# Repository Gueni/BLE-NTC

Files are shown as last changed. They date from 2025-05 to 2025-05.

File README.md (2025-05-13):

# 🔵 BLE-NTC Pipe Temperature Sensor

A compact, battery-powered wireless temperature sensor using an NTC T7335 thermistor and a NINA-B112 BLE module. Designed to clip onto pipes and transmit real-time temperature data via Bluetooth Low Energy (BLE).

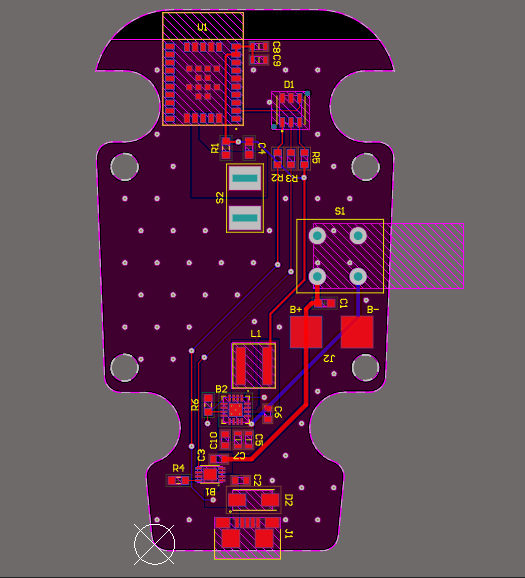
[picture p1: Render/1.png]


## 📦 Overview

This device is a clamp-on wireless temperature sensor for pipes, built around:

- 📡 **NINA-B112**: u-blox BLE module (based on Nordic nRF52832)
- 🌡️ **NTC T7335**: 10kΩ thermistor for precise surface temperature sensing
- 🔋 Battery-powered for low-power remote monitoring
- ⚙️ Custom PCB designed for mechanical stability and thermal coupling

---

## 🛠️ Features

- Accurate pipe surface temperature monitoring
- BLE GATT server for real-time temperature broadcasting
- Low-power design (sleep/wake modes)
- Compact, clamp-mountable PCB layout
- Thermal paste contact zone for improved temperature accuracy

---

## 🔧 Hardware Specs

| Feature | Description |
|---|---|
| **Sensor** | NTC T7335 (10kΩ @ 25°C, B ≈ 3977K) |
| **BLE Module** | NINA-B112-00B-00 (internal antenna) |
| **MCU** | Nordic nRF52832 (inside NINA-B112) |
| **Power Supply** | CR2032 coin cell / AA battery / 3.3V ext. |
| **ADC Interface**| Voltage divider with 10kΩ precision resistor |
| **Mounting** | Pipe clamp + thermal interface pad/paste |
| **Firmware** | BLE custom service with temperature char. |

---

## 📡 BLE Service Description

**Custom BLE GATT Service: `0x181A` (Environmental Sensing)**  
| Characteristic | UUID | Format | Description |
|---|---|---|---|
| Temperature | `0x2A6E` | `int16_t` x100 | Pipe surface temperature in °C |
| Battery Level (opt.) | `0x2A19` | `uint8_t` | Battery percentage |
| Device Info (opt.) | `0x180A` | - | Firmware version, model, etc.  |

---

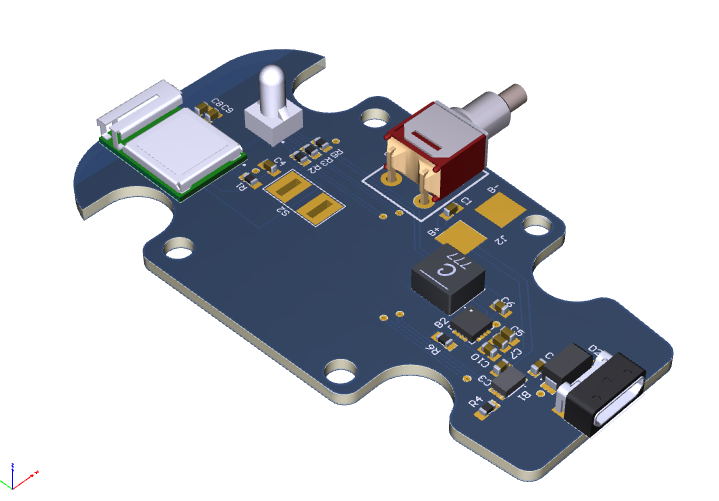
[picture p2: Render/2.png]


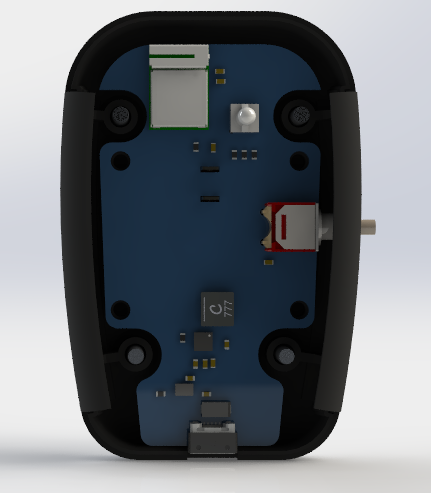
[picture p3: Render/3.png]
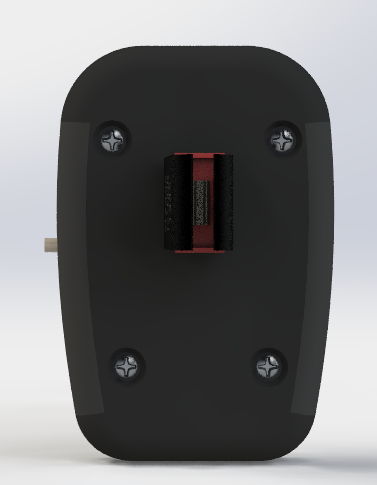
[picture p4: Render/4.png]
 | 

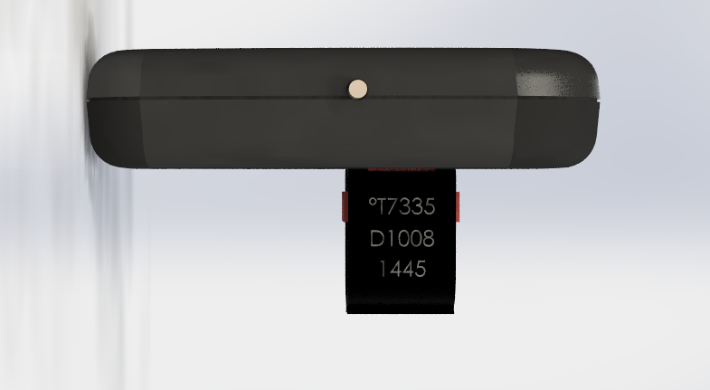
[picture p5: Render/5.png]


---

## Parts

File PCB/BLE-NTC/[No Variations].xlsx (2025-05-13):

Designator | Quantity | DES | FTP | MAN | MANREF | NOTE | SUP | SUPREF | TOL | Value 1 | Value 2
C1, C2 | 2 | Multilayer Ceramic Capacitors MLCC - SMD/SMT 4.7UF 16V 10% 0603 | 0603 | Murata Electronics | GRM188C71C475KE21D | _ | Mouser | 81-GRM188C71C475KE1D | 10% | 4.7uF | 16V
C3, C4 | 2 | 06035C103JAT2A - Condensateur céramique multicouche CMS, 10000 pF, 50 V, 0603 [1608 Metric], ± 5%, X7R | 0603 | MULTICOMP | 06035C103JAT2A | _ | Farnell | 1833871 | 5% | 10nF | 50V
C5, C6, C13 | 3 | C0603X104K8RACTU - Condensateur céramique multicouche CMS, 0.1 µF, 10 V, 0603 [1608 Metric], ± 10%, X7R | 0603 | KEMET | C0603X104K8RACTU | _ | Farnell | 2904937 | 10% | 100nF | 10V
C11 | 1 | Multilayer Ceramic Capacitors MLCC - SMD/SMT 0603 22uF 6.3volts *Derate Voltage/Temp | 0603 | Murata Electronics | GRM188R60J226MEA0D | In Stock | Mouser | 81-GRM188R60J226ME0D | 20% | 22uF | 6V3
C12 | 1 | Multilayer Ceramic Capacitors MLCC - SMD/SMT 0603 10uF 35volts *Derate Voltage/Temp | 0603 | Murata Electronics | GRM188R6YA106MA73D | _ | Mouser | 81-GRM188R6YA106MA3D | 20% | 10uF | 35V
C14 | 1 | Multilayer Ceramic Capacitors MLCC - SMD/SMT 50V 430pF 0603 C0G 0.02 | 0603 | KEMET | C0603C431G5GACTU | In Stock | Mouser | 80-C0603C431G5G | 2% | 430pF | 50V
D1 | 1 | WL-SFTW SMD Full-color TOP LED Waterclear, size 5050, Red & Green & Blue, 120deg | _ | Wurth Elektronik | 150353M153300 | In Stock | Mouser | 710-150353M153300 | _ | 100 mA | _
D2 | 1 | ESD Suppressors / TVS Diodes HJ Temp Transil ESD Suppressors / TVS Diodes HJ Temp Transil | SMA | STMicroelectronics | SMA6J5.0CA-TR | In Stock | Mouser | 511-SMA6J5.0CA-TR | _ | 13.4 V | 600W
J1 | 1 | USB Connectors USB MICRO B TYPE RECPT | SMD | Amphenol Commercial Products | GMCBA058211230HHR | In Stock | Mouser | 523-GMCBA05821123HHR | _ | _ | _
J2 | 1 | Embases et logements de câbles WR-PHD 2.54mm Hdr 6P Dual Str Gold | THT | Wurth Electronics | 61300621121 | In Stock | Mouser | 710-61300621121 | _ | 6pts | _
J3 | 1 | _ | _ | _ | _ | _ | _ | _ | _ | _
L2 | 1 | Fixed Inductors 2.2uH 20% 9.7A 14.5mOhms AEC-Q200 | _ | Coilcraft | XAL5030-222MEB | In Stock | Mouser | 994-XAL5030-222MEB | 20 % | 2.2uH | 9.2 A
Q1 | 1 | NXP NX3008NBK MOSFET, N CH, 30V, 400MA, SOT23 | SOT-23 | NXP | NX3008NBK | In Stock | Farnell | 2069541 | _ | 400mA | 30V
R1 | 1 | YAGEO (PHYCOMP) RC0603FR-0710KL RESISTANCE COUCHE EPAISSE 10K 0.1W 1% | 0603 | YAGEO | RC0603FR-0710KL | _ | Farnell | 9238603 | 1% | 10K | 0.1W
R2 | 1 | Thick Film Resistors 806KOHM 1/10WATT 1% | 0603 | Bourns | CR0603-FX-8063ELF | In Stock | Mouser | 652-CR0603-FX8063ELF | 1% | 806K | 0.1W
R3 | 1 | Thick Film Resistors 1/10watt 160ohms 1% | 0603 | Vishay / Dale | CRCW0603160RFKEA | In Stock | Mouser | 71-CRCW0603-160-E3 | 1% | 160R | 0,1W
R4 | 1 | YAGEO (PHYCOMP) RC0603FR-072K2L RESISTANCE COUCHE EPAISSE 2.2K 0.1W 1% | 0603 | YAGEO | RC0603FR-072K2L | _ | Farnell | 9238522 | 1% | 2K2 | 0.1W
R5, R7 | 2 | Thick Film Resistors 1/10watt 5.1ohms 5% | 0603 | Vishay / Dale | CRCW06035R10JNEA | In Stock | Mouser | 71-CRCW0603J-5.1-E3 | 5% | 5R1 | 10W
R6 | 1 | Thin Film Resistors .1W 2Mohms 1% 0603 50ppm | 0603 | Vishay / Beyschlag | MCT06030C2004FP500 | In Stock | Mouser | 594-MCT06030C2004FP5 | 1% | 2 M | 0.125W
R9 | 1 | YAGEO (PHYCOMP) RC0603FR-07100KL RESISTANCE COUCHE EPAISSE 100K 0.1W 1% | 0603 | YAGEO | RC0603FR-07100KL | _ | Farnell | 9238727 | 1% | 100K | 0.1W
S1 | 1 | Negative temperature coefficient thermistor | _ | Honeywell | T7335 D1008 | _ | _ | _ | _ | _ | _
S2 | 1 | Pushbutton Switches SPDT ON-ON PC MNT | _ | E-Switch | 800CSP1B6M6QE | _ | E-Switch | 800CSP1B6M6QE | _ | _ | _
U1 | 1 | Battery Management Charge mgnt contr Battery Management Charge mgnt contr | DFN | Microchip Technology | MCP73831T-2ACI/MC | In Stock | Mouser | 579-MCP73831T-2ACIMC | _ | _ | _
U2 | 1 | MOD BLE 5.0 NORDIC NRF52832 SOC | _ | U-Blox | NINA-B112-00B-00 | In Stock | Digi-Key | 672-NINA-B112-00B-00CT-ND | _ | _ | _
U4 | 1 | Switching Voltage Regulators 3-17V 3A SD Cnvrtr | VQFN-16 | Texas Instruments | TPS62132RGTR | In Stock | Mouser | 595-TPS62132RGTR | _ | _ | _

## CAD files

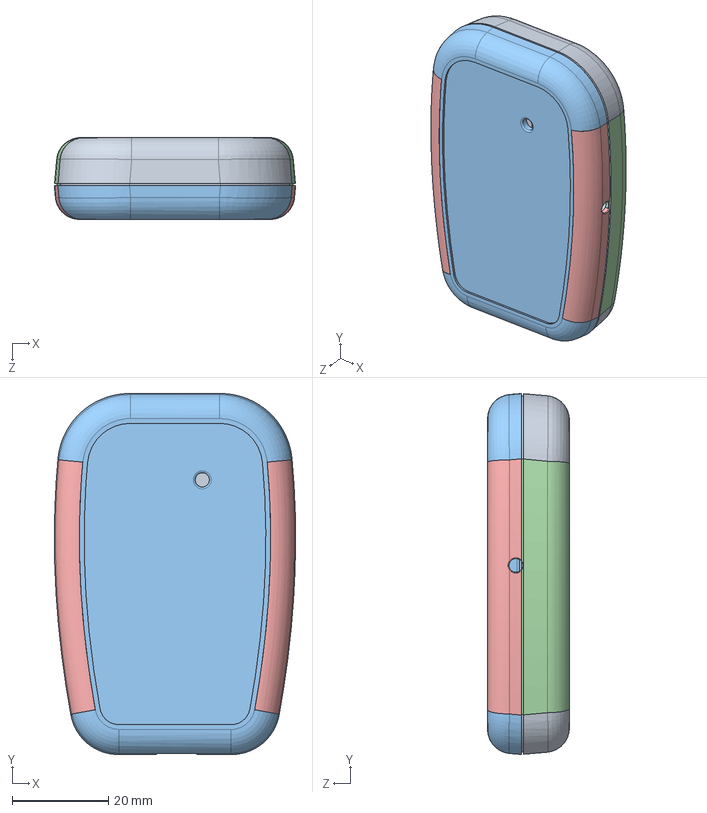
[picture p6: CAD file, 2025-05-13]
3D/Assem2 -nopcb.SLDASM
50.1 x 75.0 x 17.0 mm
1553AA BOTTOM.stp
SC1553A (screw #4X 1_2'' OH).stp x 4
1553AA TOP.stp
1553AA BOTTOM GRIP.stp
1553AA TOP GRIP.stp

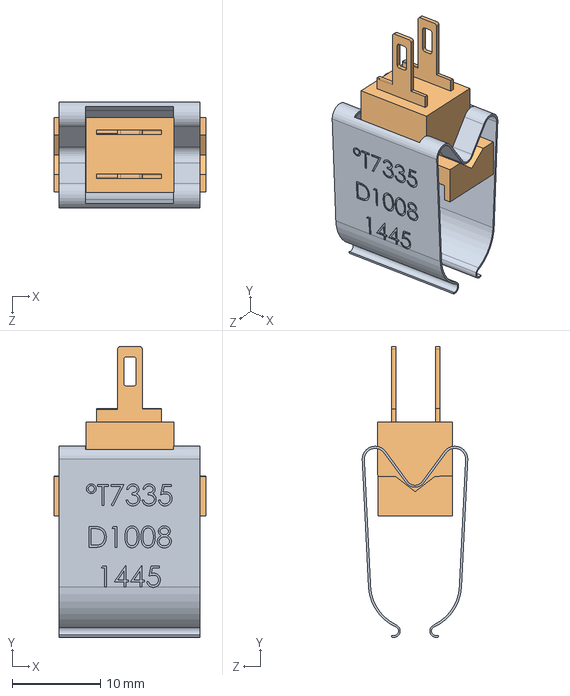
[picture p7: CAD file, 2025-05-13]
3D/T7335D_Assembly.SLDASM
17.2 x 33.0 x 12.0 mm
T7335D
T7335D_sensor

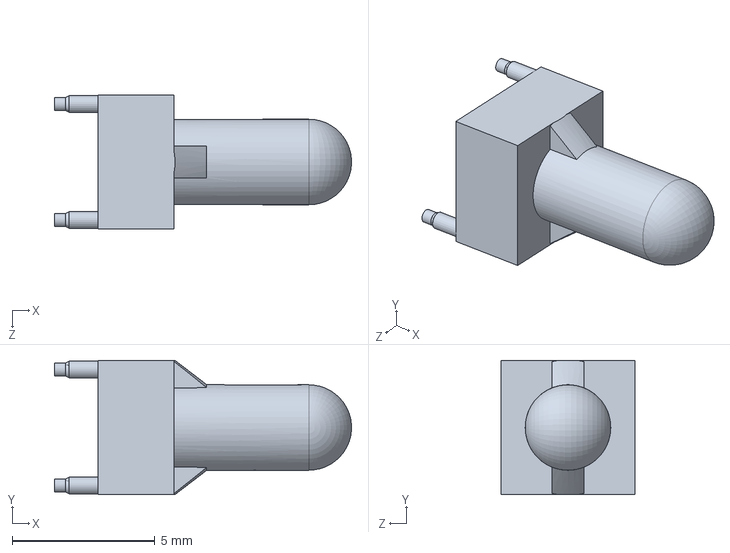
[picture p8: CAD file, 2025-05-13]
3D/VLP-350-R.SLDPRT
10.4 x 4.70 x 4.70 mm

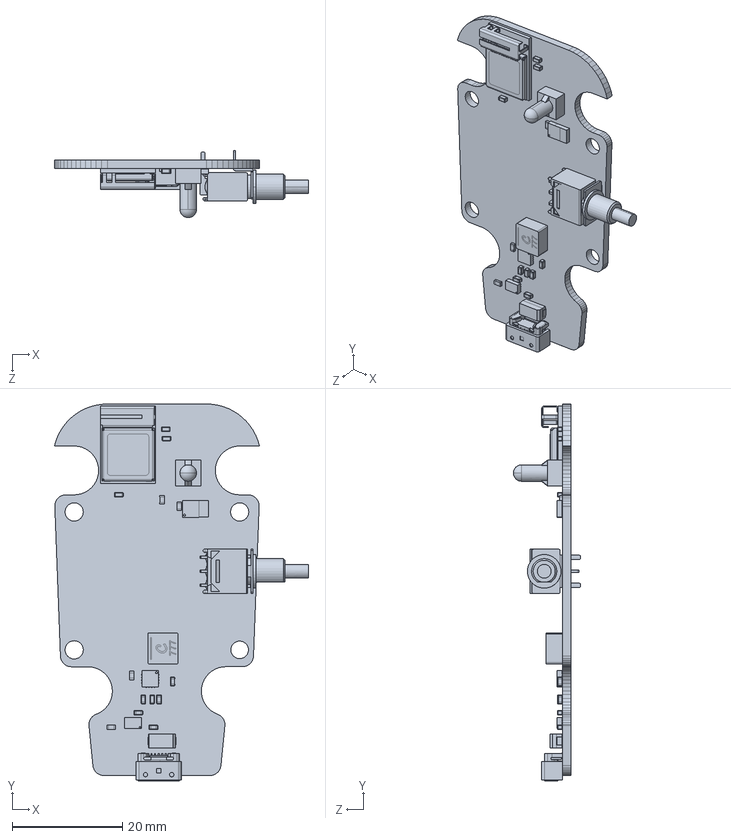
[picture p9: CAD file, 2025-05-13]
3D/Part50.SLDPRT
46.1 x 68.3 x 12.2 mm

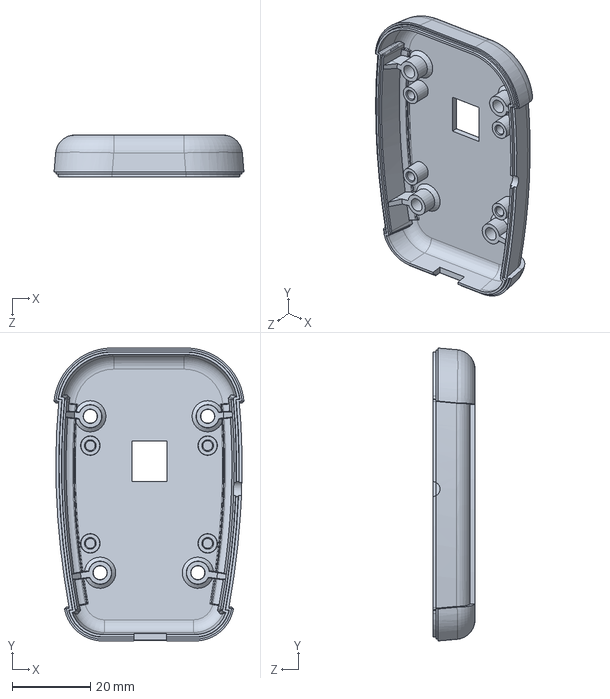
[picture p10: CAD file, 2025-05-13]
3D/1553AA BOTTOM.stp.SLDPRT
48.5 x 74.9 x 10.8 mm

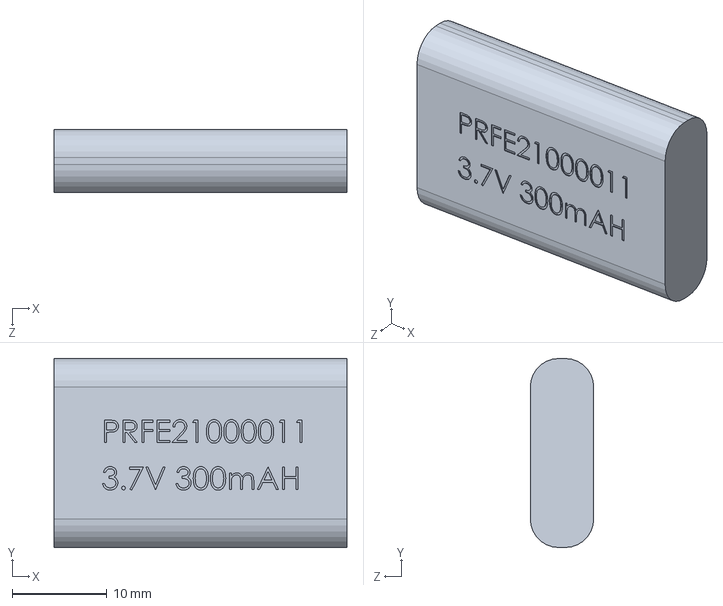
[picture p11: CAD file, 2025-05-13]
3D/Battery_30.0x20.0x6.7.SLDPRT
31.0 x 20.0 x 6.70 mm

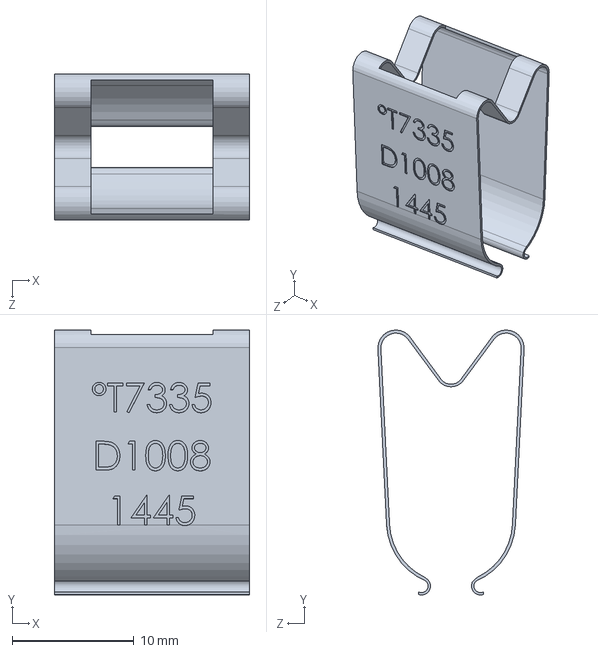
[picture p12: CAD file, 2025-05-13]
3D/T7335D.SLDPRT
16.0 x 21.7 x 12.0 mm

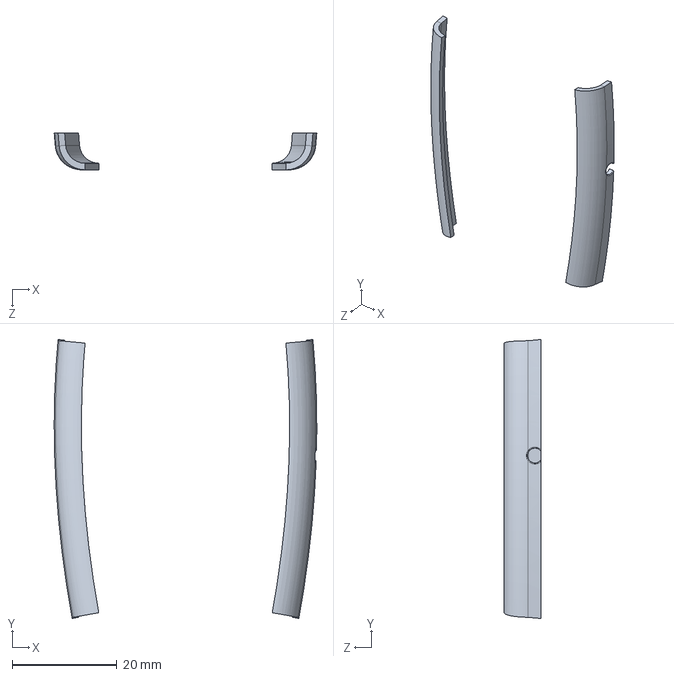
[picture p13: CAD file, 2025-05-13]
3D/1553AA TOP GRIP.stp.SLDPRT
50.1 x 53.3 x 7.00 mm

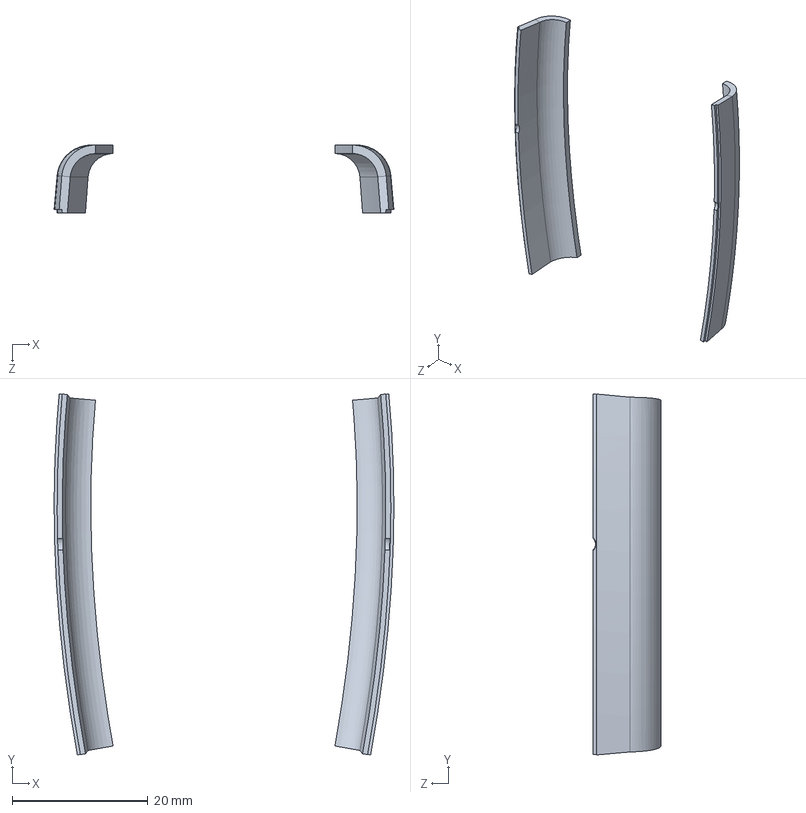
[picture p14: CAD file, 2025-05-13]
3D/1553AA BOTTOM GRIP.stp.SLDPRT
50.0 x 53.2 x 10.0 mm

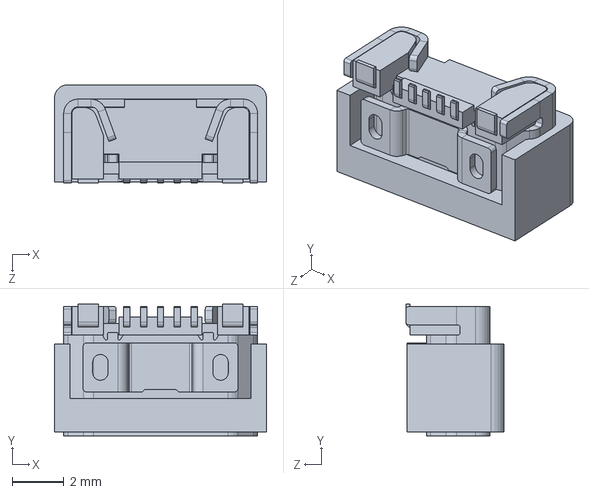
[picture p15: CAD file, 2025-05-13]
3D/gmcba058xx1230hhr.stp.SLDPRT
8.20 x 5.10 x 3.80 mm

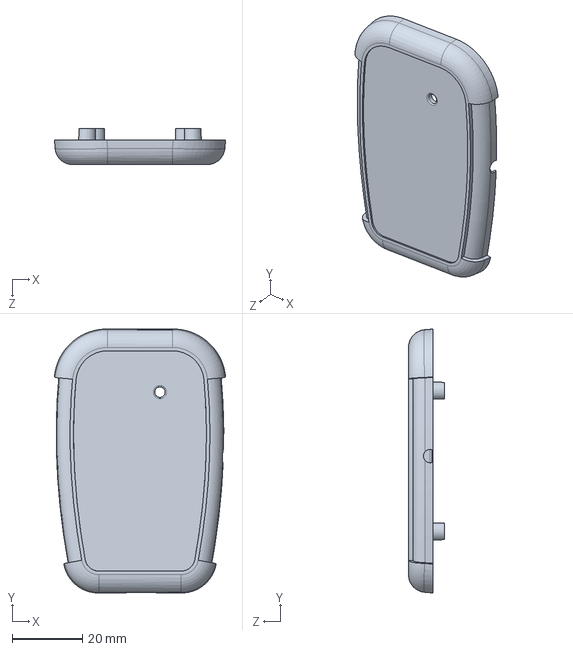
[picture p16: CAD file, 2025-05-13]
3D/1553AA TOP.stp.SLDPRT
48.6 x 75.0 x 10.2 mm

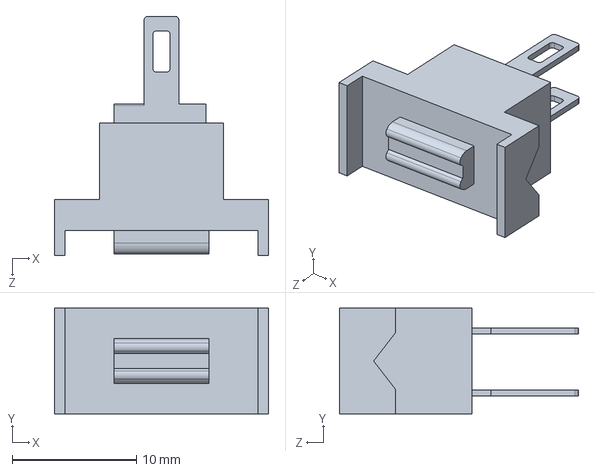
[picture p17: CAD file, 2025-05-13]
3D/T7335D_sensor.SLDPRT
17.2 x 8.50 x 19.2 mm

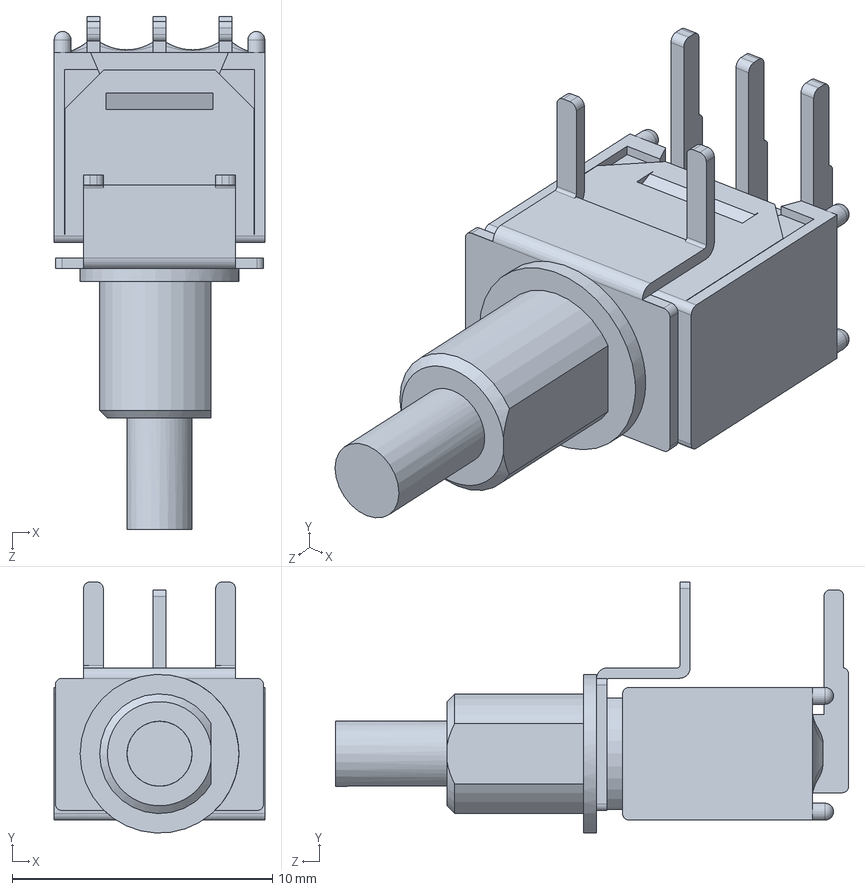
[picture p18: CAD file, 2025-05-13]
3D/800CSP1B6M6xE.stp.SLDPRT
8.10 x 9.65 x 19.7 mm

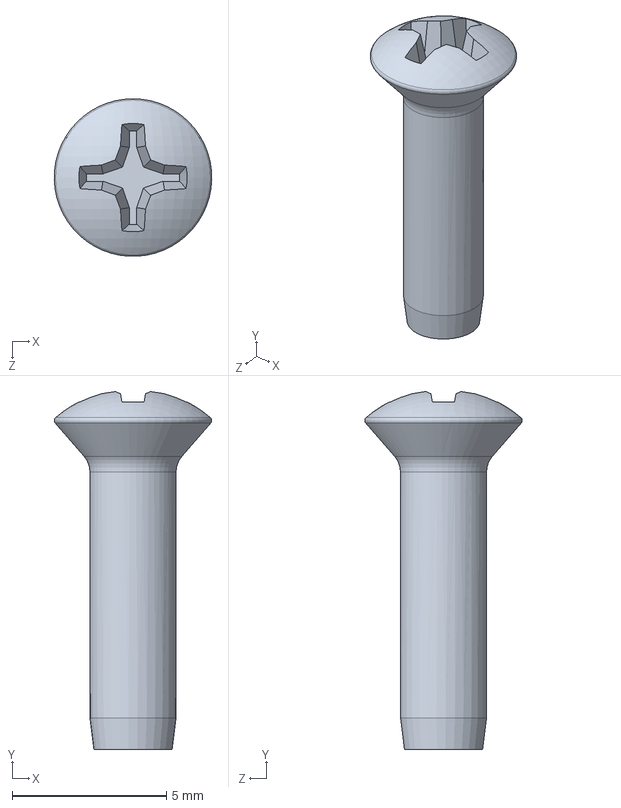
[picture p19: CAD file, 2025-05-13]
3D/SC1553A (screw #4X 1_2'' OH).stp.SLDPRT
5.10 x 11.6 x 5.10 mm

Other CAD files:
3D/00019202.SLDASM
3D/Assembly_without_PCB.SLDDRW
3D/T7335D_Assembly.SLDPRT

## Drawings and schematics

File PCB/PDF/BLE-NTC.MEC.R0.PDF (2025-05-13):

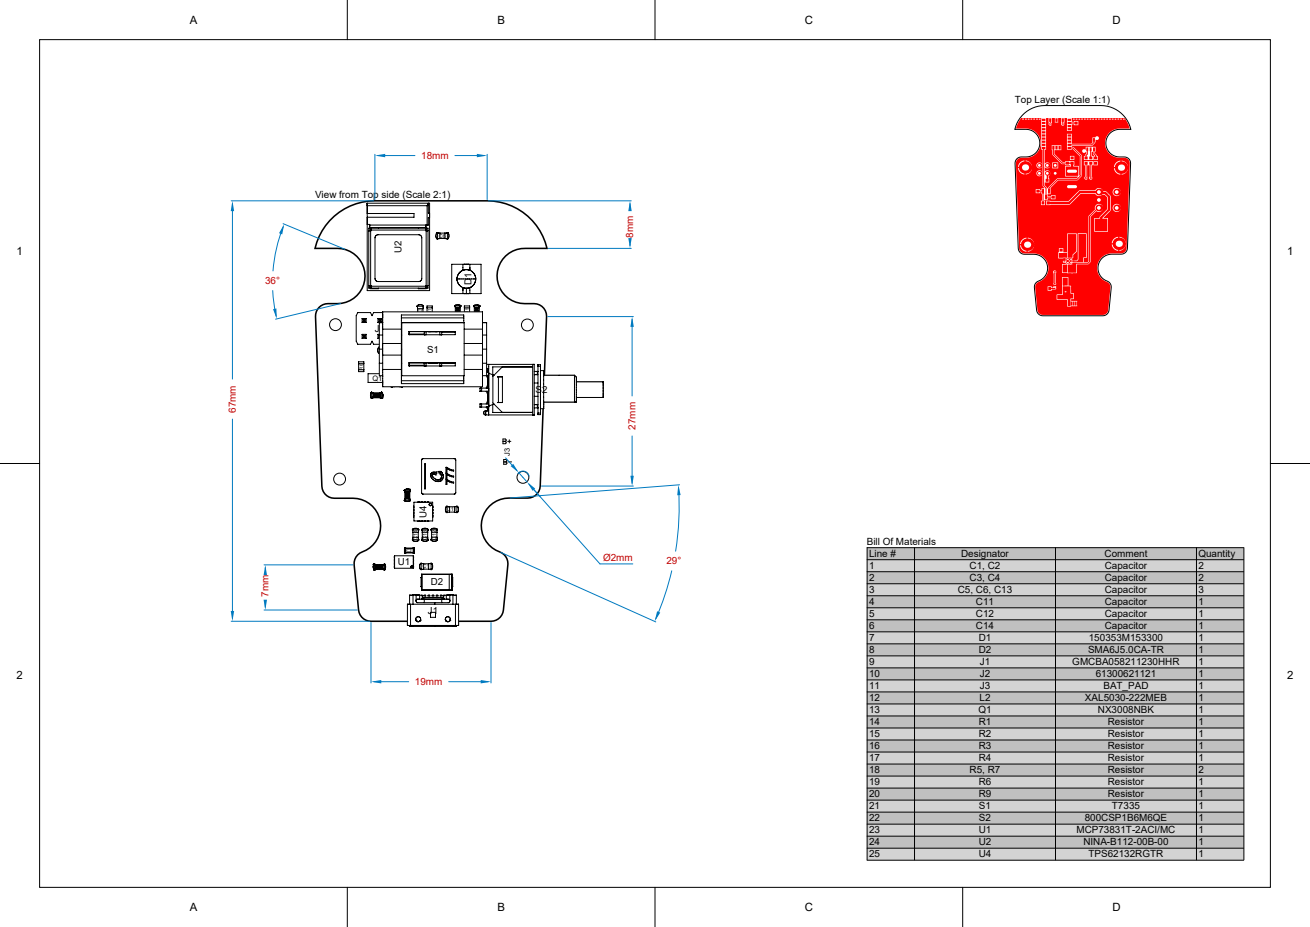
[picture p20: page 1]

View from Top side (Scale 2:1)

Line # 123456789 | C5, C6, C13 | Capacitor

D2 | SMA6J5.0CA-TR | Quantity 2231111111111111121111111
Designator | Comment
C1, C2 | Capacitor
C3, C4 | Capacitor

C11 | Capacitor
C12 | Capacitor
C14 | Capacitor
D1 | 150353M153300

J1 | GMCBA058211230HHR

10 | J2 | 61300621121
11 | J3 | BAT_PAD
12 | L2 | XAL5030-222MEB
13 | Q1 | NX3008NBK
14 | R1 | Resistor
15 | R2 | Resistor
16 | R3 | Resistor
17 | R4 | Resistor
18 | R5, R7 | Resistor
19 | R6 | Resistor
20 | R9 | Resistor
21 | S1 | T7335
22 | S2 | 800CSP1B6M6QE
23 | U1 | MCP73831T-2ACI/MC
24 | U2 | NINA-B112-00B-00
25 | U4 | TPS62132RGTR

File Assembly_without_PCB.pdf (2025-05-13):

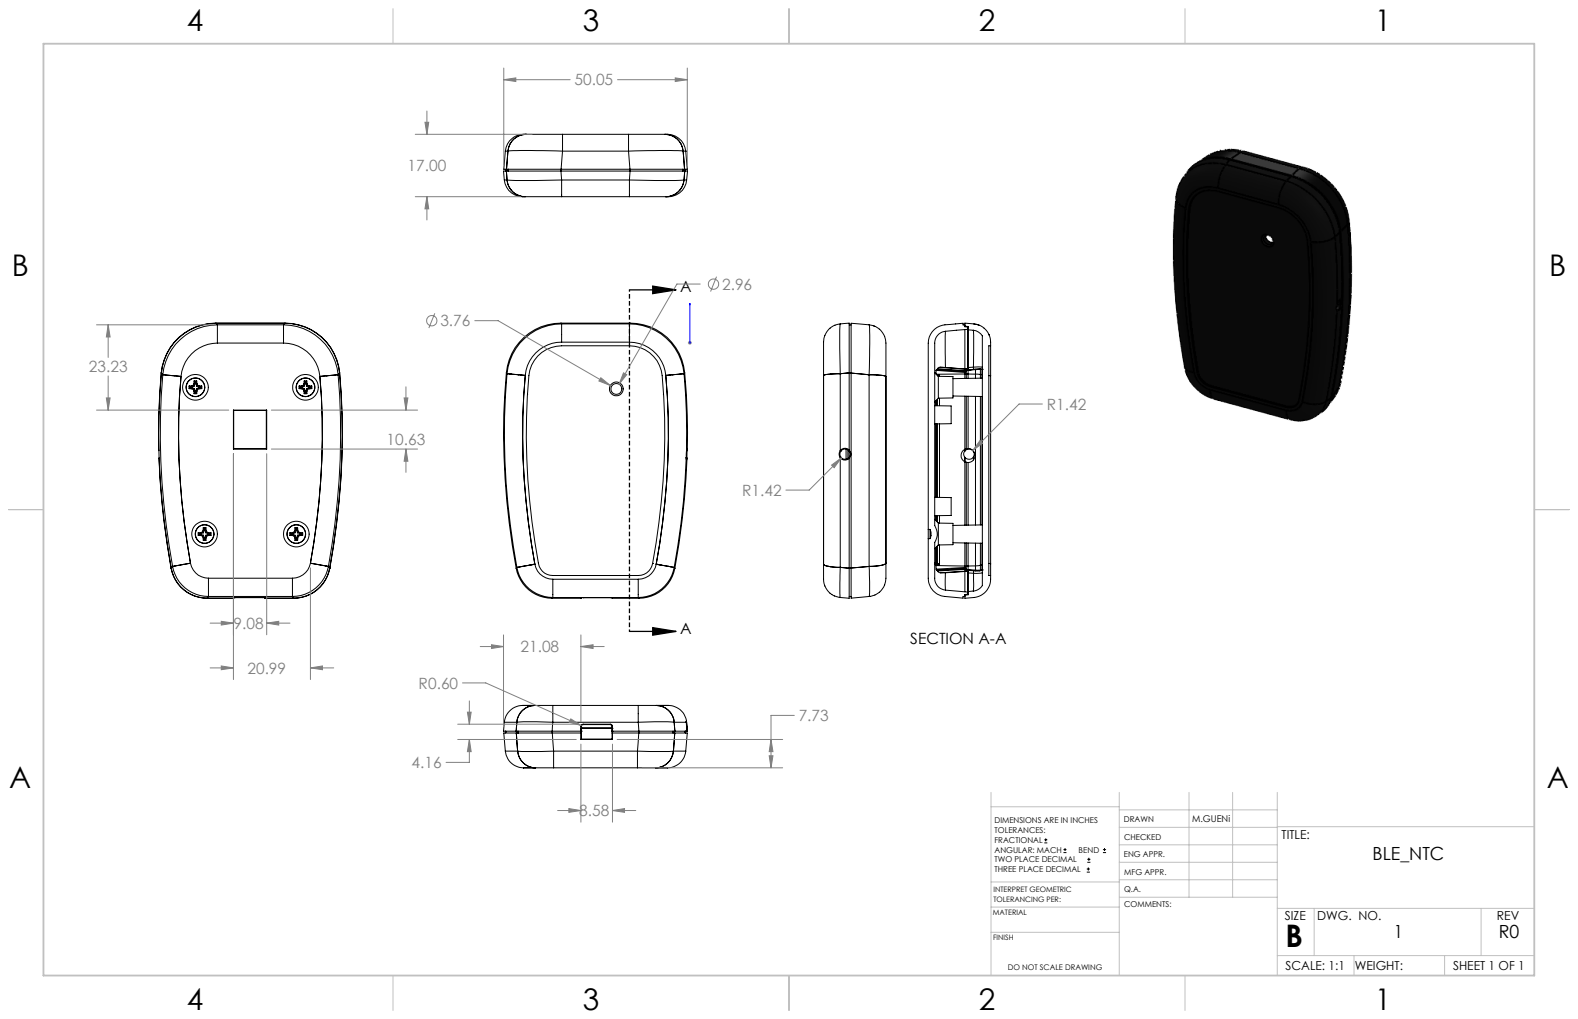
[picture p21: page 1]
SECTION A-A; SHEET 1 OF 1; SCALE: 1:1; WEIGHT:; DWG. NO.; REV

DIMENSIONS ARE IN INCHES TOLERANCES: FRACTIONAL ANGULAR: MACH BEND TWO PLACE DECIMAL THREE PLACE DECIMAL | DRAWN | M.GUENi

CHECKED | | | TITLE: BLE_NTC

ENG APPR.
MFG APPR.

INTERPRET GEOMETRIC TOLERANCING PER: | Q.A.

DO NOT SCALE DRAWING

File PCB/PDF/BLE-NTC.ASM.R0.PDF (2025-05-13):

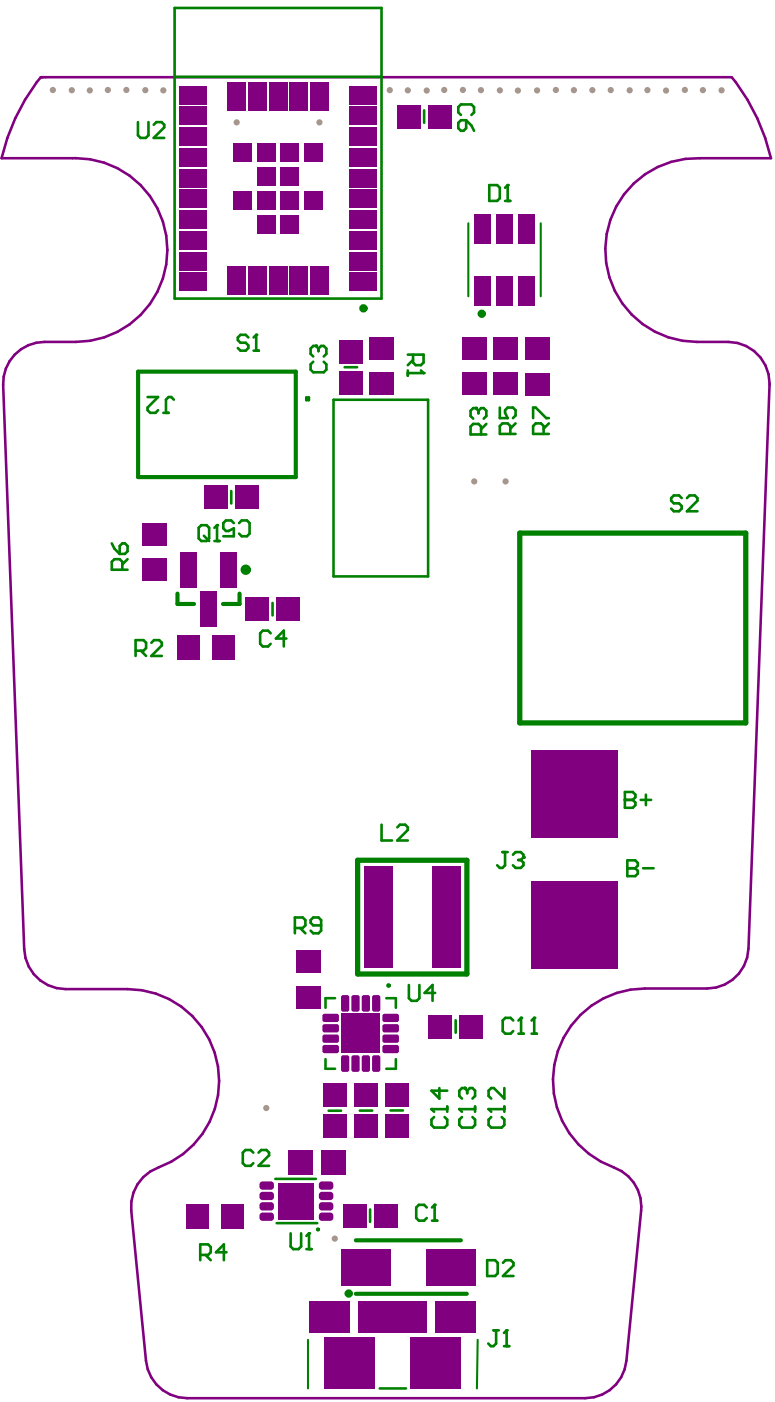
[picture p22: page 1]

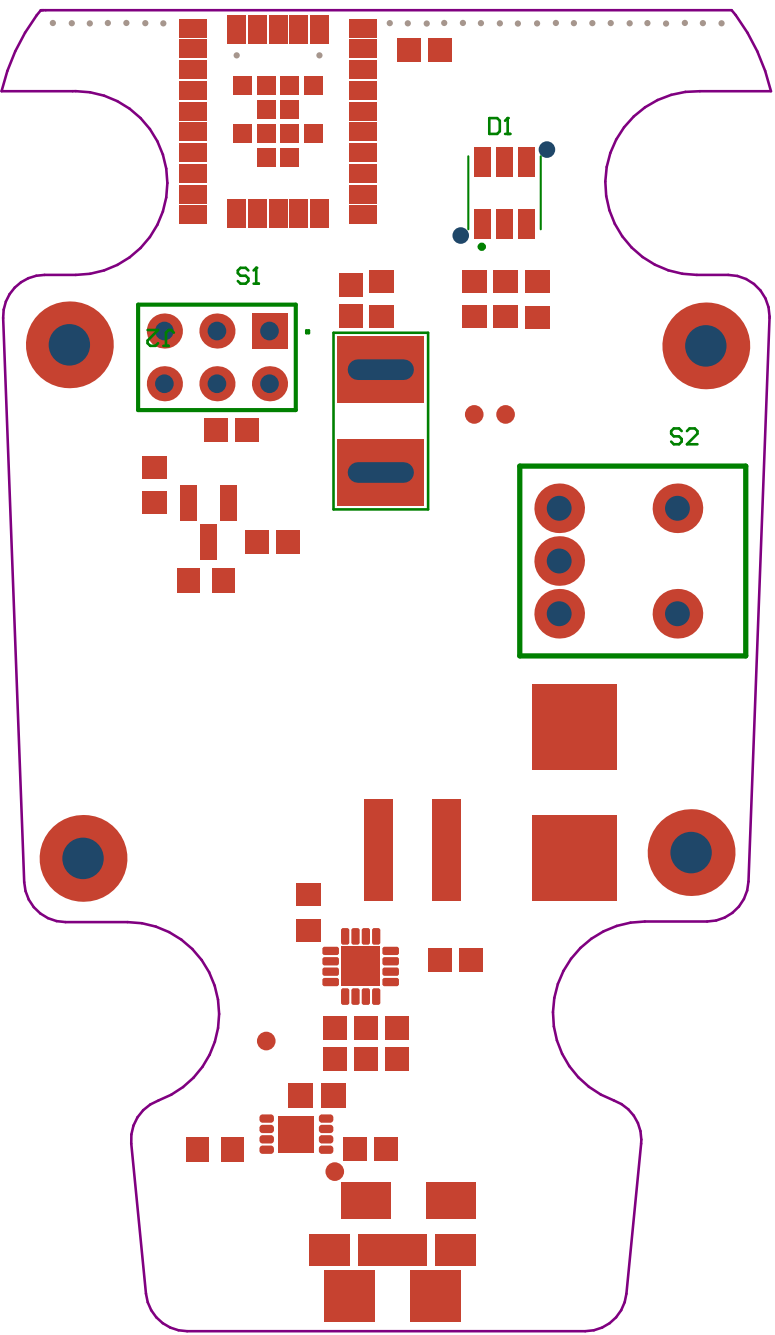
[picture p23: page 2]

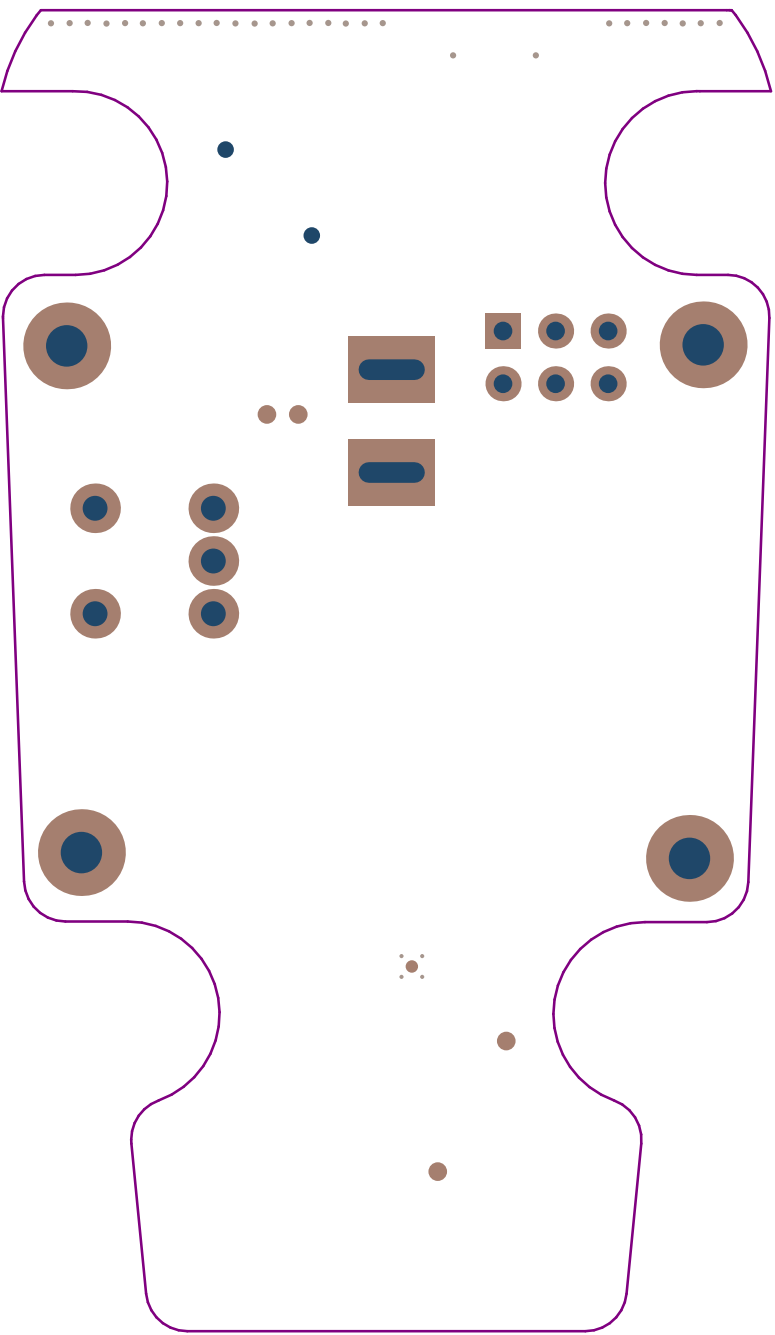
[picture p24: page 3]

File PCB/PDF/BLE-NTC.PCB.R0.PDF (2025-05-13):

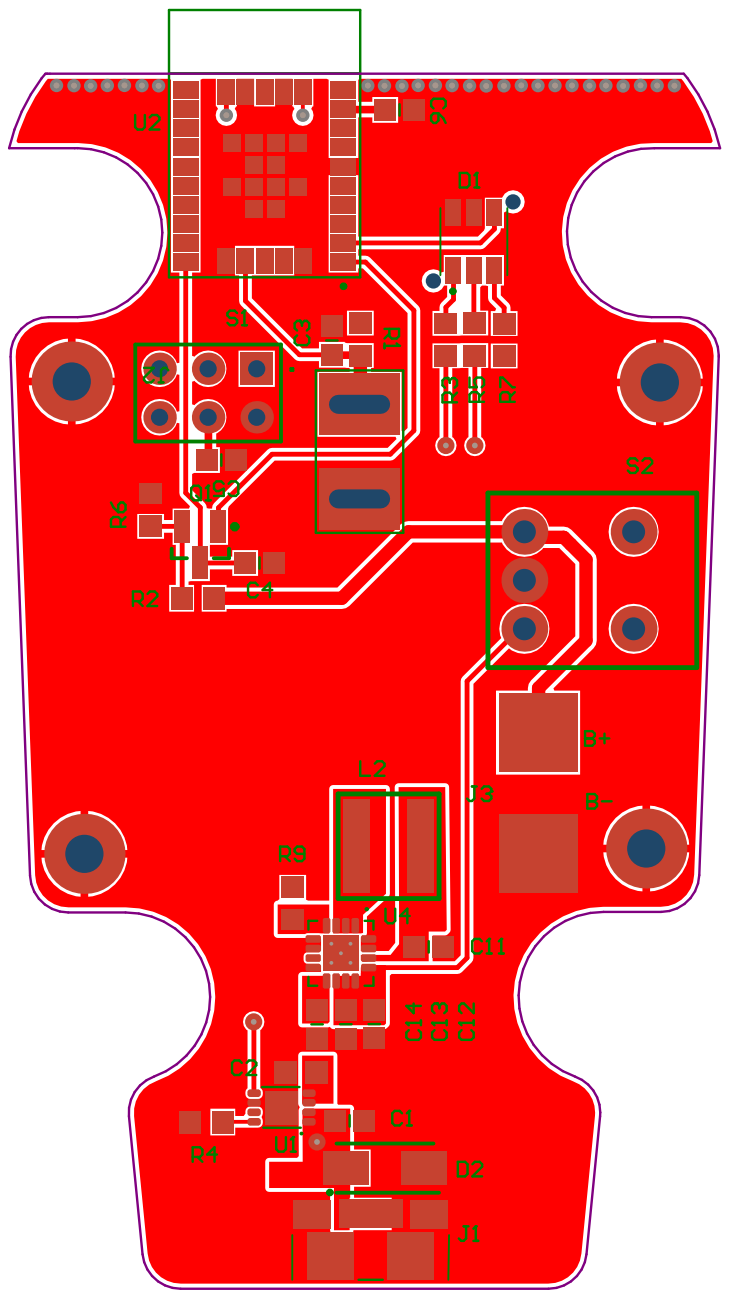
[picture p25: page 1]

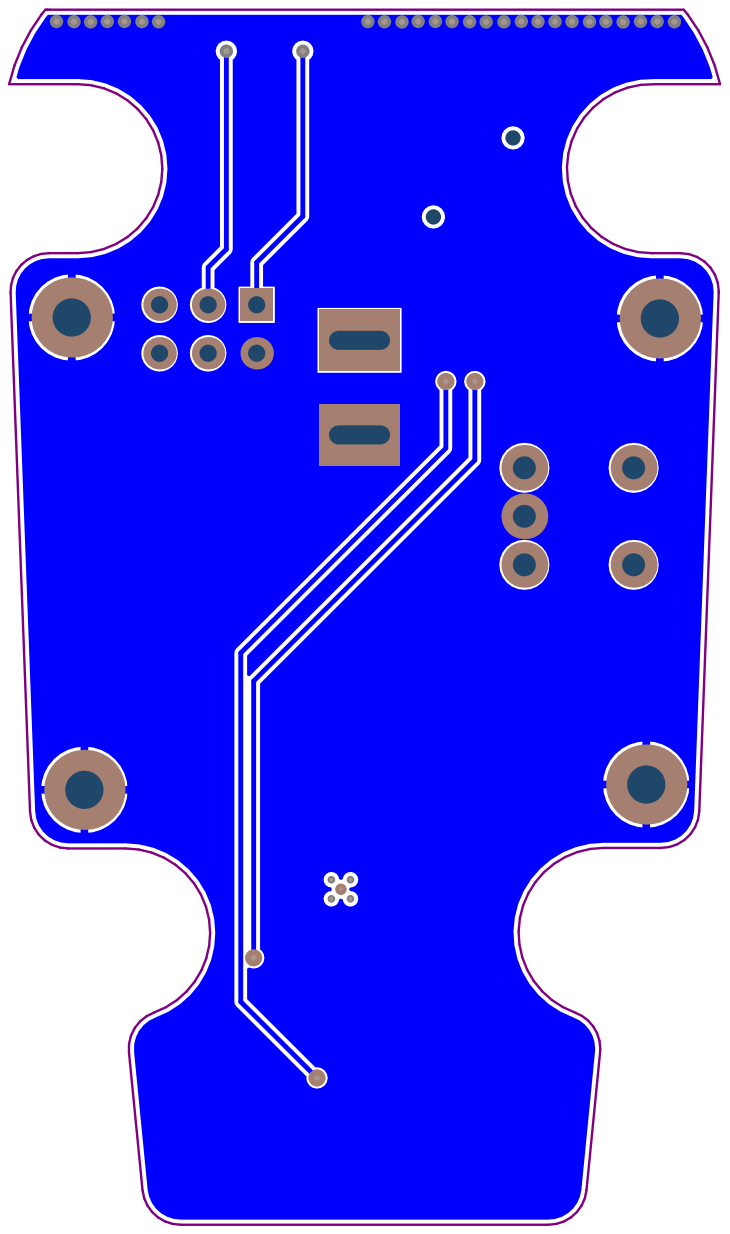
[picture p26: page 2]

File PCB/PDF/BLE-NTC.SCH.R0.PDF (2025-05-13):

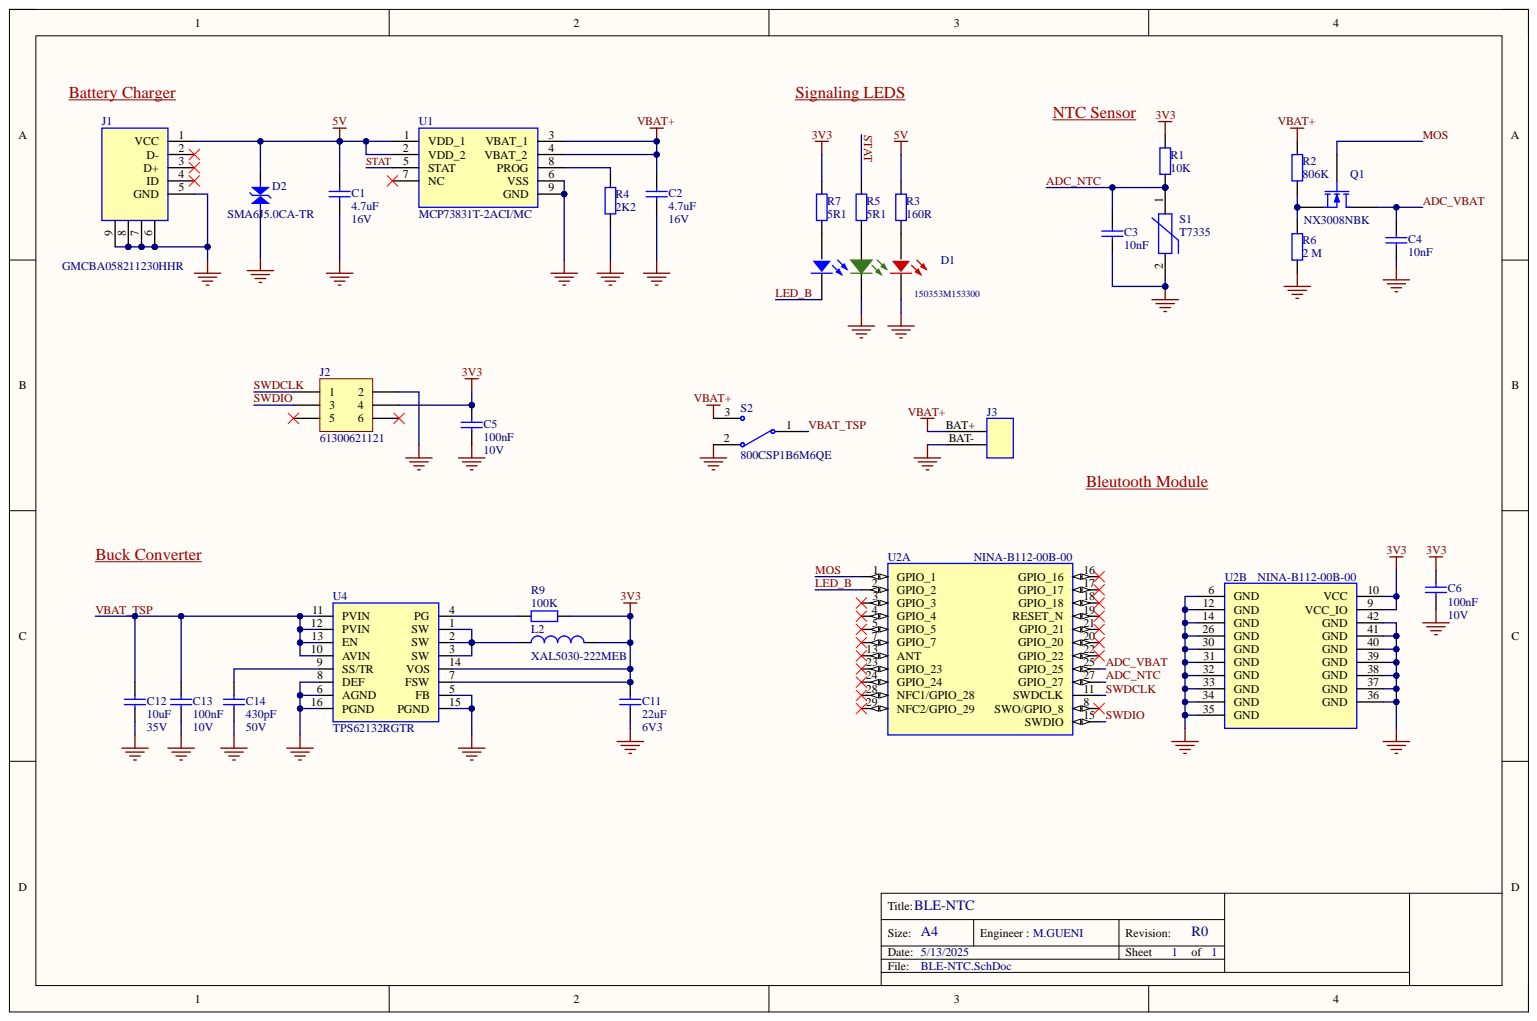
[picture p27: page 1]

Size: A4 | Engineer : M.GUENI | Revision: R0

Date: 5/13/2025 | | Sheet 1 of 1

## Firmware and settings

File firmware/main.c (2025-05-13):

#include "nrf.h"
#include "nrf_gpio.h"
#include "nrf_delay.h"
#include "nrf_saadc.h"
#include "app_timer.h"
#include "ble_advdata.h"
#include "ble_srv_common.h"
#include "ble_bas.h"
#include "ble_conn_params.h"
#include "nrf_pwr_mgmt.h"
#include "nrf_sdh.h"
#include "nrf_sdh_ble.h"
#include "app_error.h"
#include "ble_temp_service.h"

#define ADC_INPUT NRF_SAADC_INPUT_AIN0
#define APP_BLE_CONN_CFG_TAG 1
#define DEVICE_NAME "BLE-NTC"
#define TEMP_MEAS_INTERVAL APP_TIMER_TICKS(5000)

BLE_TEMP_SERVICE_DEF(m_temp_service);
APP_TIMER_DEF(m_temp_timer_id);

static uint16_t m_conn_handle = BLE_CONN_HANDLE_INVALID;

void saadc_init(void)
{
    nrf_saadc_channel_config_t config = NRF_SAADC_CHANNEL_CONFIG_SE(NRF_SAADC_INPUT_AIN0);
    nrf_saadc_enable();
    nrf_saadc_channel_init(0, &config);
}

float adc_to_temp(int16_t adc_value)
{
    float Vref = 3.3;
    float R_fixed = 10000.0;
    float Vadc = ((float)adc_value / 1023.0) * Vref;

    float R_ntc = (Vref * R_fixed / Vadc) - R_fixed;

    float B = 3977.0;
    float T0 = 298.15; // 25°C in Kelvin
    float R0 = 10000.0;

    float temp_K = 1.0 / (1.0 / T0 + (1.0 / B) * log(R_ntc / R0));
    return temp_K - 273.15; // Return °C
}

void temp_timer_handler(void *p_context)
{
    nrf_saadc_value_t adc_val;
    nrf_saadc_sample_convert(0, &adc_val);

    float temp = adc_to_temp(adc_val);
    int16_t temp_int = (int16_t)(temp * 100); // GATT format: int16_t x100

    ble_temp_service_temperature_update(&m_temp_service, temp_int);
}

void timers_init(void)
{
    app_timer_init();
    app_timer_create(&m_temp_timer_id, APP_TIMER_MODE_REPEATED, temp_timer_handler);
}

void ble_stack_init(void)
{
    nrf_sdh_enable_request();
    uint32_t ram_start = 0;
    nrf_sdh_ble_default_cfg_set(APP_BLE_CONN_CFG_TAG, &ram_start);
    nrf_sdh_ble_enable(&ram_start);
}

void gap_params_init(void)
{
    ble_gap_conn_params_t conn_params = {0};
    ble_gap_conn_sec_mode_t sec_mode;
    BLE_GAP_CONN_SEC_MODE_SET_OPEN(&sec_mode);

    sd_ble_gap_device_name_set(&sec_mode, (const uint8_t *)DEVICE_NAME, strlen(DEVICE_NAME));
    sd_ble_gap_ppcp_set(&conn_params);
}

void services_init(void)
{
    ble_temp_service_init(&m_temp_service);
}

void advertising_start(void)
{
    // Init advertising here (not shown for brevity)
}

int main(void)
{
    saadc_init();
    timers_init();
    ble_stack_init();
    gap_params_init();
    services_init();
    advertising_start();

    app_timer_start(m_temp_timer_id, TEMP_MEAS_INTERVAL, NULL);

    while (true)
    {
        nrf_pwr_mgmt_run();
    }
}

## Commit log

2025-05-13 ble sdk
    [00019202.SLDASM, 1553AA BOTTOM GRIP.stp.SLDPRT, 1553AA BOTTOM.stp.SLDPRT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]
2025-05-13 Remove obsolete Status Report file from PCB directory
2025-11-04 kicad version added
